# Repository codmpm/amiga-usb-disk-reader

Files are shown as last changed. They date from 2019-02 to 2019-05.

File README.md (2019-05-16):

# Amiga USB Floppy Disk Reader

> __abandoned in favor of https://nickslabor.niteto.de/projekte/adf-copy/__

This is a PCB I've designed to work with the marvelous idea, firmware and software 
from Rob Smith: https://github.com/RobSmithDev/ArduinoFloppyDiskReader 

It's nothing fancy but has some benefits I think that do matter:

* integrated _real_ FTDI232RL for communication and AVR flashing
* Decent DC/DC converter that can handle up to 5V/1A and wide input voltage (7-36V). 
This is the more power friendly way, as some drives demand more than the 
max. 500mA USB delivers
* Switchable to USB power if desired
* ATMega 328p on board with [Optiboot](https://github.com/Optiboot/optiboot)
* Solderpads for 4-pin Molex 3.5" connector with routed VCC. So if the drive needs 12V you 
can use a 12V power source

Of course this is only a fun project and does not aim to be the _best_ solution for Rob's 
approach, but it made my life easier.

This is the first release, as the PCB's have to be tested. I'm currently waiting for the 
prototypes.

## PCB

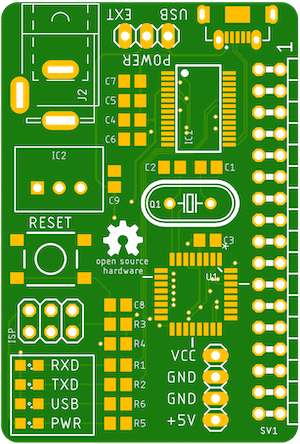
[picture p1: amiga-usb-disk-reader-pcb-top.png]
PCB top


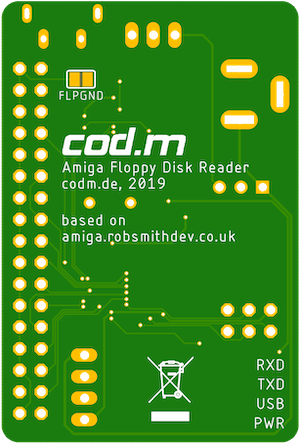
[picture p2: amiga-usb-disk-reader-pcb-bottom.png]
PCB bottom


## Contributing

1. Fork it!
2. Create your feature branch: `git checkout -b my-new-feature`
3. Commit your changes: `git commit -am 'Add some feature'`
4. Push to the branch: `git push origin my-new-feature`
5. Submit a pull request :D

## Credits
Patrik Mayer, cod.m GmbH, 2019 

Rob Smith, who had the initial idea and wrote the software this is using

## License
[CC-BY-SA](https://creativecommons.org/licenses/by-sa/3.0/)

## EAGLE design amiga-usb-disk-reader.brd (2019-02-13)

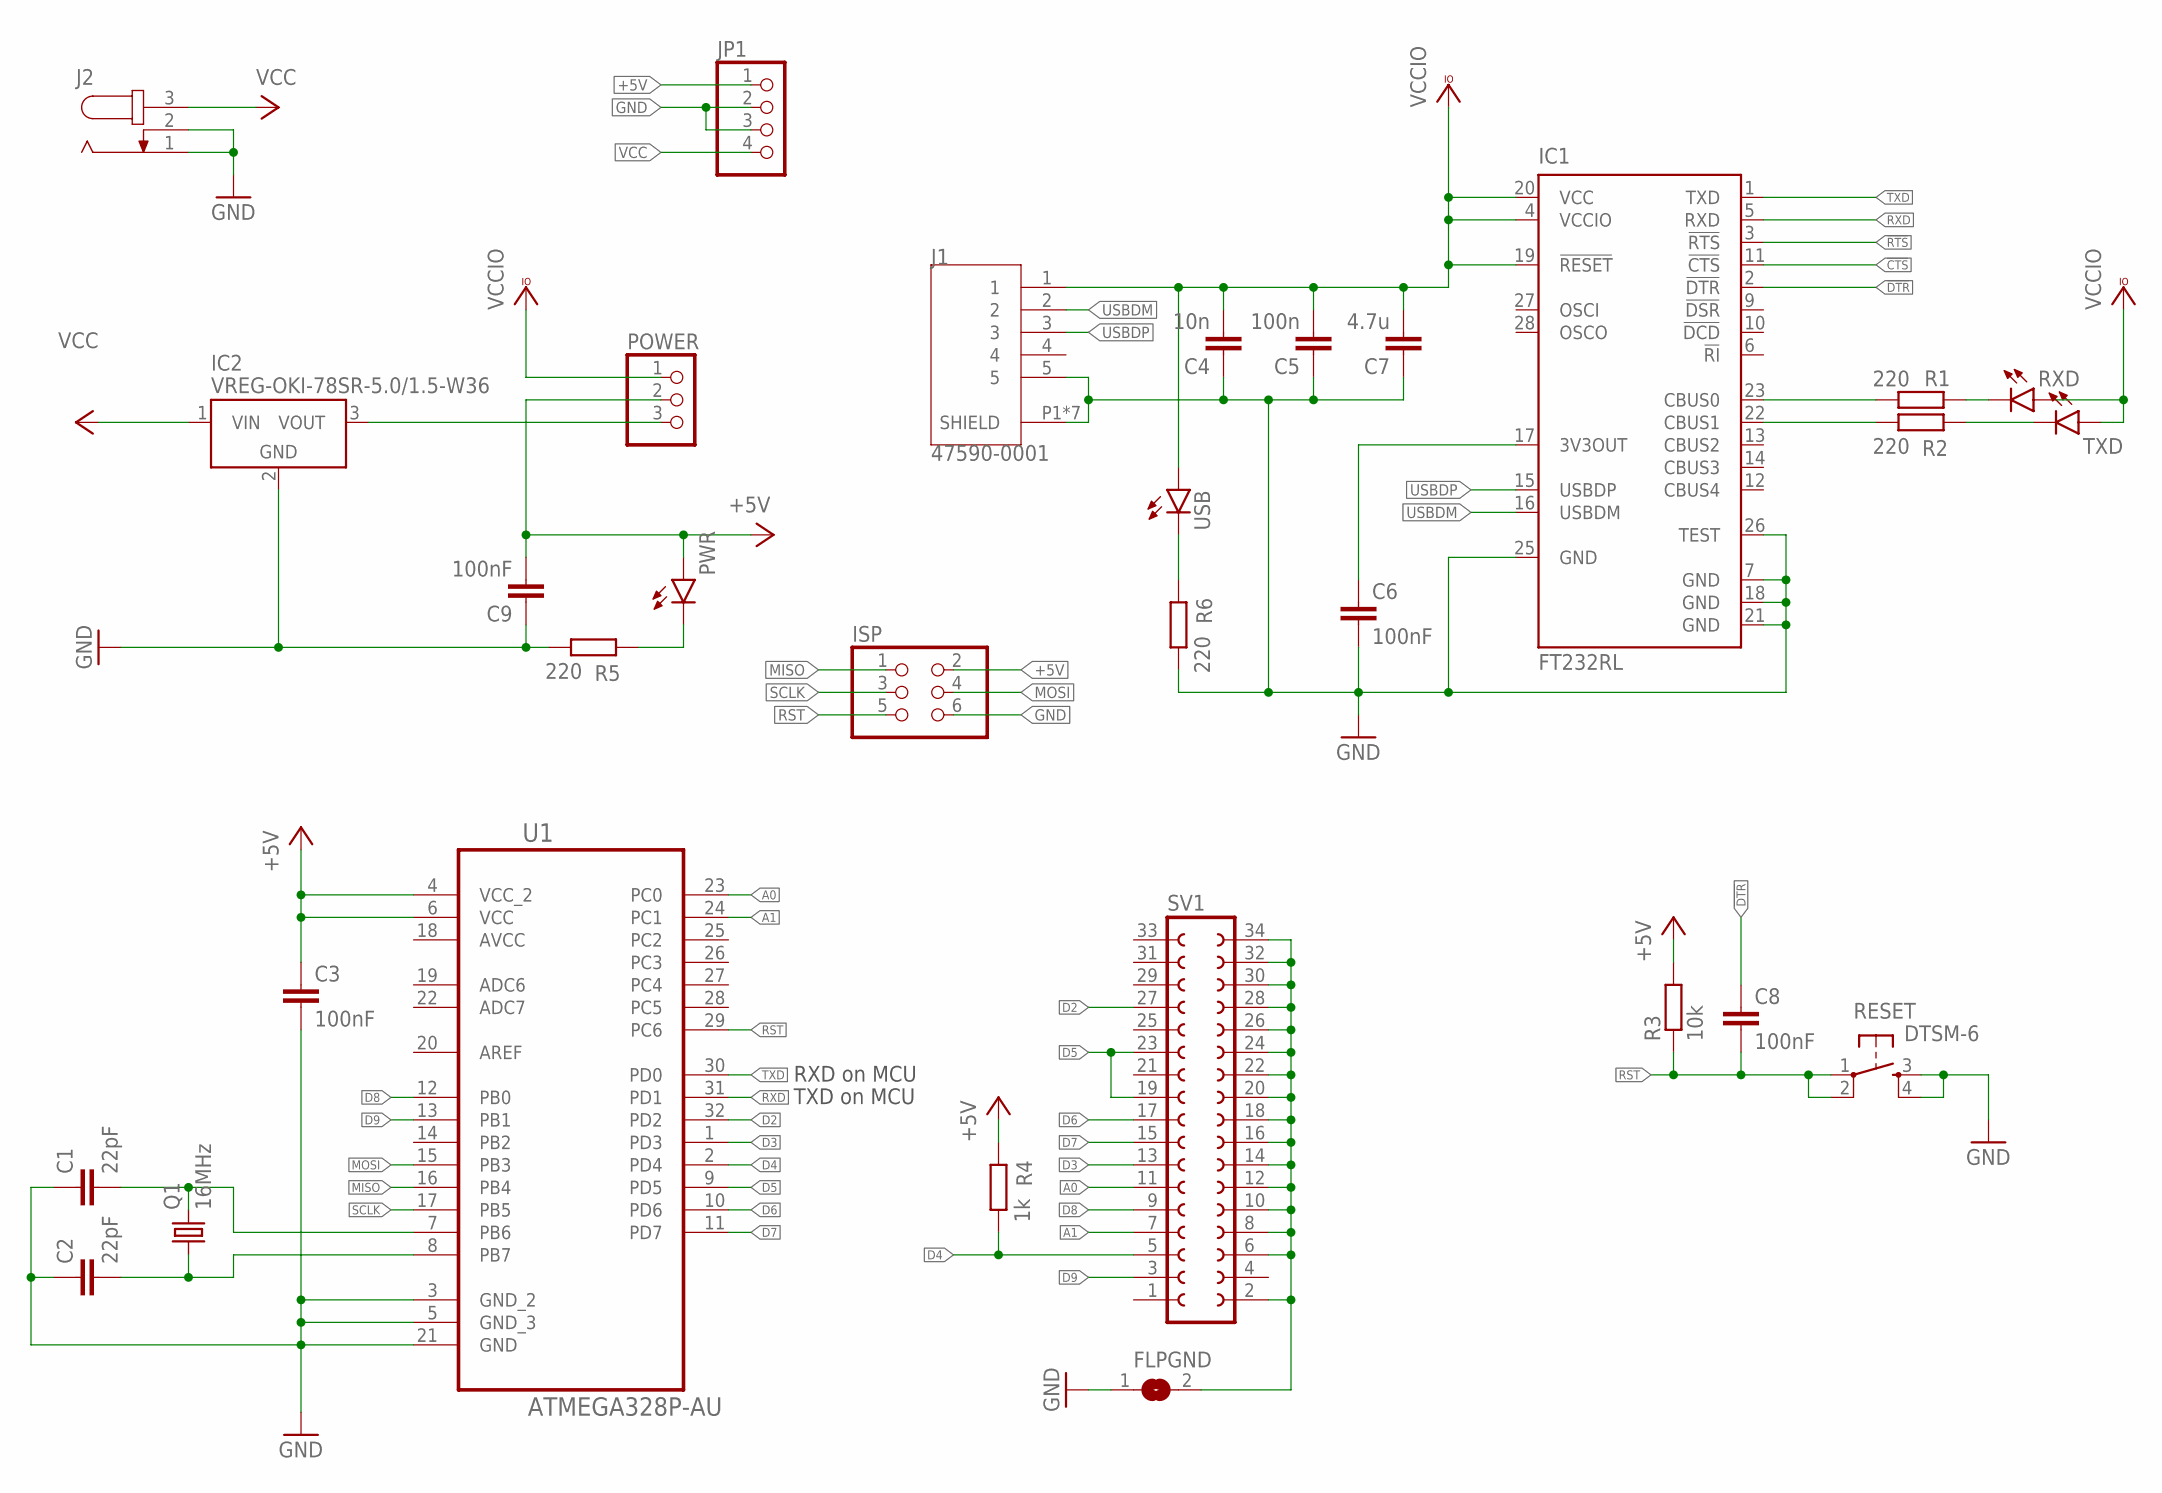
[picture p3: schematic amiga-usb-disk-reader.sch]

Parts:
C1, C2: 22pF; C0805
C3, C6, C8, C9: 100nF; C0805
C4: 10n; C0805
C5: 100n; C0805
C7: 4.7u; C0805
FLPGND: SJ
IC1: FT232RL; SSOP28
IC2: VREG-OKI-78SR-5.0/1.5-W36; OKI-78SR
ISP: PINHD-2X3; 2X03
J1: 47590-0001; MOLEX_47590-0001
J2: JACK-PLUG0; SPC4077
JP1: PINHD-1X4; 1X04
POWER: PINHD-1X3; 1X03
PWR: LEDSML0805; SML0805
Q1: 16MHz; HC49U70
R1, R2, R5, R6: 220; R0805
R3: 10k; R0805
R4: 1k; R0805
RESET: DTSM-6
RXD: LEDSML0805; SML0805
SV1: FE17-2W
TXD: LEDSML0805; SML0805
U1: ATMEGA328P-AU; QFP80P900X900X120-32N
USB: LEDSML0805; SML0805

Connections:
!CTS: IC1.11 (!CTS)
!DTR: C8.1, IC1.2 (!DTR)
!RTS: IC1.3 (!RTS)
+5V: C3.1, C9.2, ISP.2, JP1.1, POWER.2, PWR.A, R3.2, R4.1, U1.4 (VCC_2), U1.6 (VCC)
A0: SV1.11, U1.23 (PC0)
A1: SV1.7, U1.24 (PC1)
AVCC: U1.18 (AVCC)
CBUS0: IC1.23 (CBUS0), R1.2
CBUS1: IC1.22 (CBUS1), R2.2
D2: SV1.27, U1.32 (PD2)
D3: SV1.13, U1.1 (PD3)
D4: R4.2, SV1.5, U1.2 (PD4)
D5: SV1.19, SV1.23, U1.9 (PD5)
D6: SV1.17, U1.10 (PD6)
D7: SV1.15, U1.11 (PD7)
D8: SV1.9, U1.12 (PB0)
D9: SV1.3, U1.13 (PB1)
GND: C1.1, C2.1, C3.2, C4.1, C5.1, C6.2, C7.1, C9.1, FLPGND.1, IC1.7 (GND), IC1.18 (GND), IC1.21 (GND), IC1.25 (GND), IC1.26 (TEST), IC2.2 (GND), ISP.6, J1.5, J1.P1 (SHIELD), J1.P2 (SHIELD), J1.P3 (SHIELD), J1.S1 (SHIELD), J1.S2 (SHIELD), J1.S3 (SHIELD), J1.S4 (SHIELD), J2.1, J2.2, JP1.2, JP1.3, R5.2, R6.2, RESET.3, RESET.4, U1.3 (GND_2), U1.5 (GND_3), U1.21 (GND)
MISO: ISP.1, U1.16 (PB4)
MOSI: ISP.4, U1.15 (PB3)
unnamed: C6.1, IC1.17 (3V3OUT)
unnamed: C2.2, Q1.1, U1.8 (PB7)
unnamed: C1.2, Q1.2, U1.7 (PB6)
unnamed: FLPGND.2, SV1.2, SV1.6, SV1.8, SV1.10, SV1.12, SV1.14, SV1.16, SV1.18, SV1.20, SV1.22, SV1.24, SV1.26, SV1.28, SV1.30, SV1.32, SV1.34
unnamed: R2.1, TXD.C
unnamed: R1.1, RXD.C
unnamed: PWR.C, R5.1
unnamed: IC2.3 (VOUT), POWER.3
unnamed: R6.1, USB.C
RST: C8.2, ISP.5, R3.1, RESET.1, RESET.2
RXD: IC1.5 (RXD), U1.31 (PD1)
SCLK: ISP.3, U1.17 (PB5)
TXD: IC1.1 (TXD), U1.30 (PD0)
USBDM: IC1.16 (USBDM), J1.2
USBDP: IC1.15 (USBDP), J1.3
VCC: IC2.1 (VIN), J2.3, JP1.4
VCCIO: C4.2, C5.2, C7.2, IC1.4 (VCCIO), IC1.19 (!RESET), IC1.20 (VCC), J1.1, POWER.1, RXD.A, TXD.A, USB.A

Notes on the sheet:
RXD on MCU
TXD on MCU

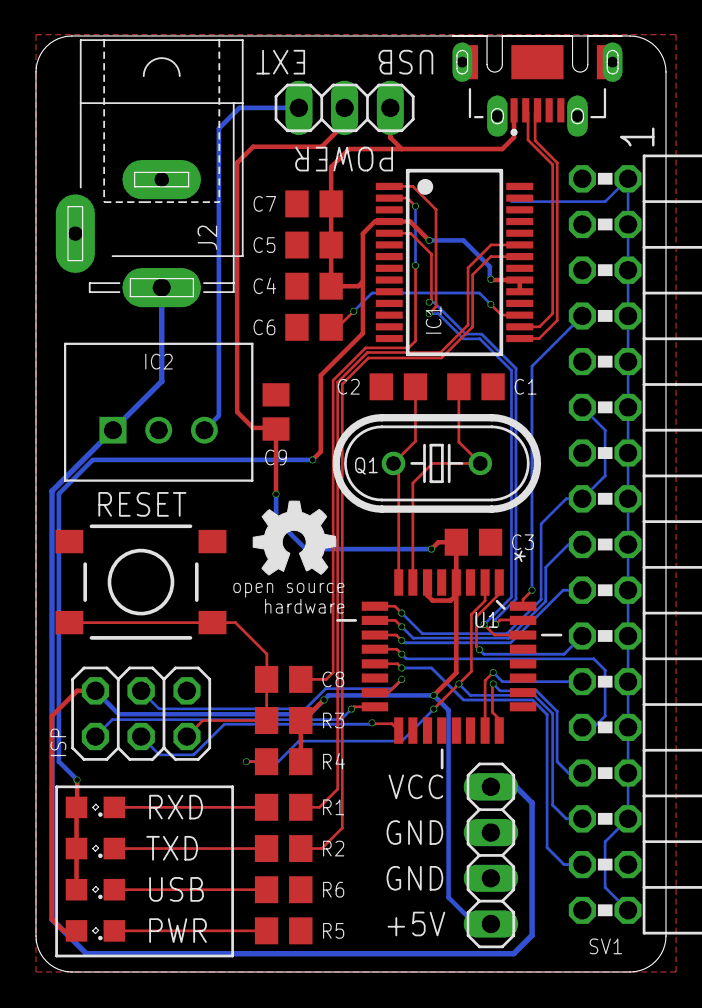
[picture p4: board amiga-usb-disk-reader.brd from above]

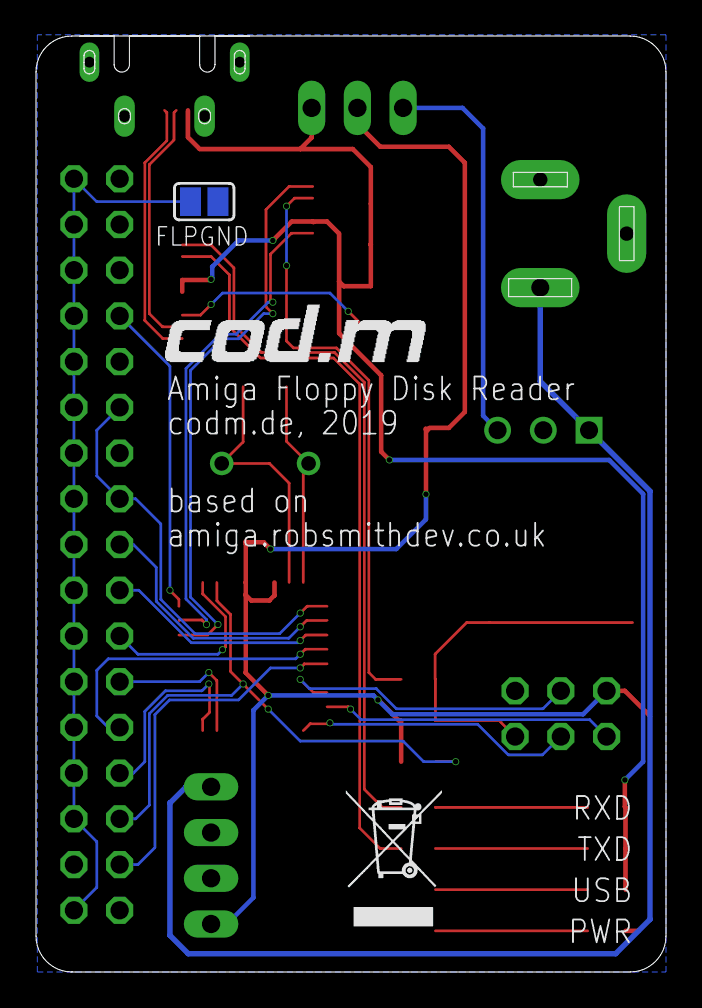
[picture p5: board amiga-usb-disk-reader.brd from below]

Board: 2 copper layers, 35.0 x 52.0 mm, 34 parts (3 on the bottom side), 34 nets.

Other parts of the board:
U$1: OSHW_5MM
U$2: WEEE-LOGO-5MM
U$3: CODM-LOGO
